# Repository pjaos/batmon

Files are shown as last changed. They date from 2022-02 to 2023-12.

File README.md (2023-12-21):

# BATMON

## Overview
The batmon device connects to a Lithium ION battery (primarily aimed at Ebike batteries) and allows the user to
trade off the lifetime of the battery against the maximum single charge. The life of a lithium ION cell
is affected by many things, the maximum charge level of the cell, the temperature of the cell, the maximum
discharge of the cell etc. The batmon device allows the user to limit the maximum charge voltage of the cell
to reduce stresses on the battery chemistry.

For example if the maximum charge voltage of a Lithium ION cell is set to 4.1
volts per cell rather than the maximum of 4.2 volts per cell then the number of charge/discharge cycles
that the battery is capable of could be doubled. The trade off for this is that you will loose about 10 %
of the range on a single charge. If set to 4.0 volts per cell then the number of charge/discharge cycles
that the battery is capable of could be increased by four times. The trade off for this is that you will
loose about 25 % of the range on a single charge. The batmon device allows the user to set this trade off
by selecting the maximum charge voltage in five 0.05 volt steps from 4.2 to 4.0 volts.

The device also ensures that the battery is not charged when to cold or hot which also limits the batteries
lifetime. Charging at temperatures of 0°C or below can also be dangerous.

As stated previously this project is primarily aimed at improving the lifetime of Ebike batteries although the hardware could be used for other battery voltages with slight changes to the software. The device provides a WiFi connection. This can connect to your home WiFi network or run in stand alone (AP) mode. The [Yview App](https://github.com/pjaos/yview/tree/master/gui) can be used (Android phone/tablet or a Windows, Linux PC) to access the state of the battery (charge voltage/current etc) and configure the device settings.

## System Requirements
An initial set of requirements for the system is shown below.

* Charge the battery to a maximum voltage of between 4.0 and 4.2 Volts, configurable by the user.
* Display the charge voltage, current and power.
* Turn off charging if the battery temperature is too cold (<= 0°C).
* Turn off charging if the battery temperature is too hot (> 45°C)g.

## Hardware.
The hardware design uses an ESP32 CPU which provides the WiFi connectivity. An ADS1115 I2C 16 bit ADC device is used to measure the battery voltage, charge current and battery temperature. A Mosfet is used to turn off the battery charge once it reaches the configured charge voltage. The case for the module was 3D printed to provide a robust mount for the module inside the battery case.

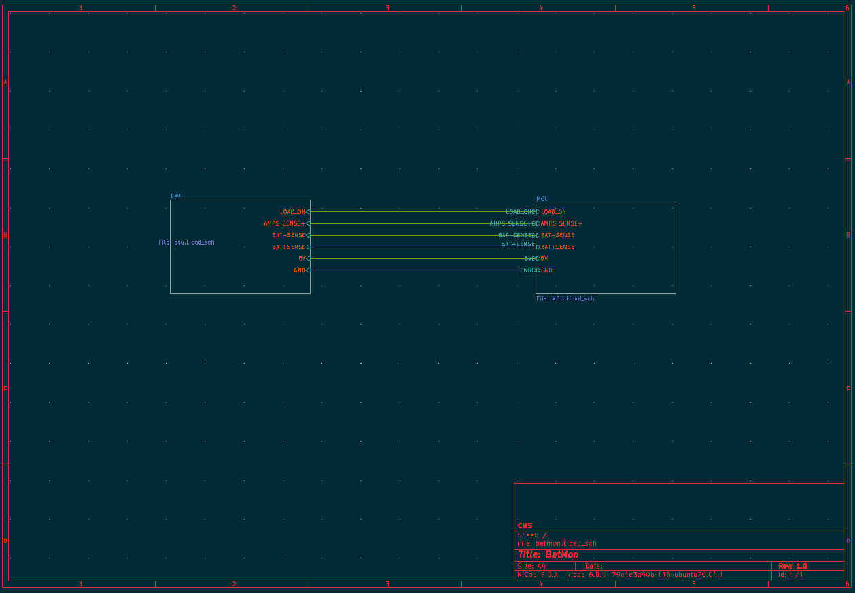
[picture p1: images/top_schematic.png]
Top Level Schematic

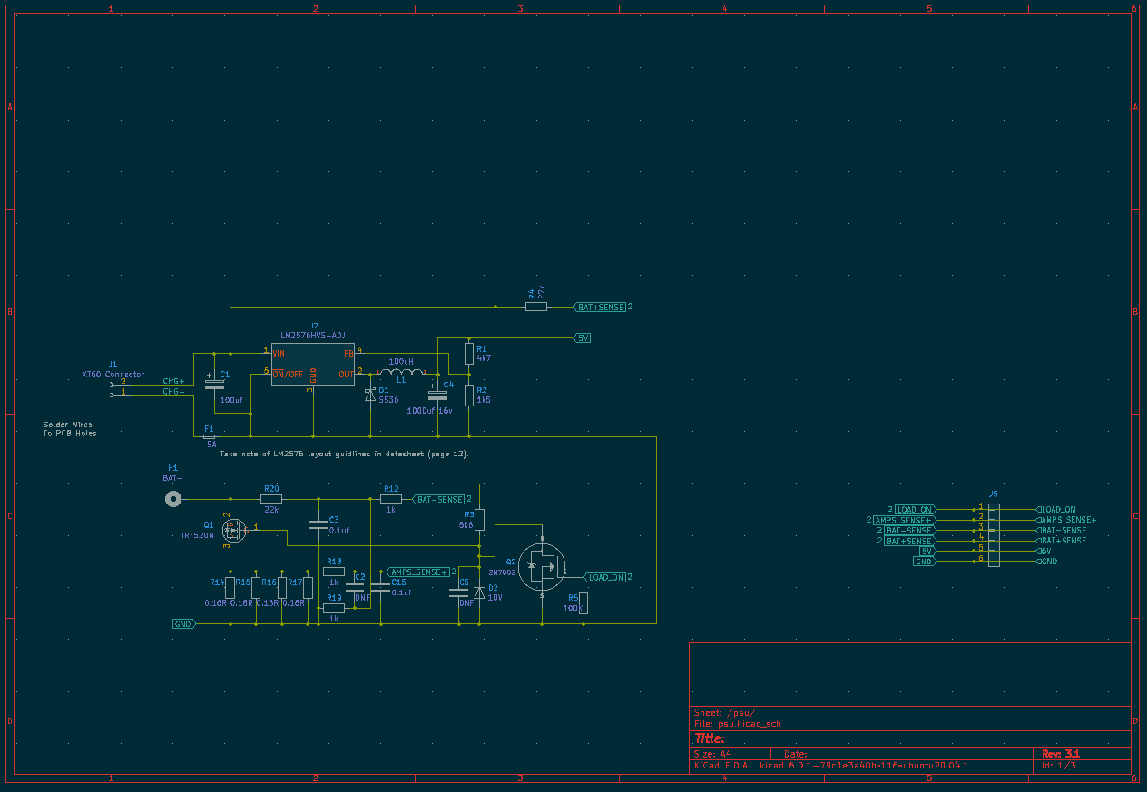
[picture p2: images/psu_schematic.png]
Top Level Schematic PSU Schematic

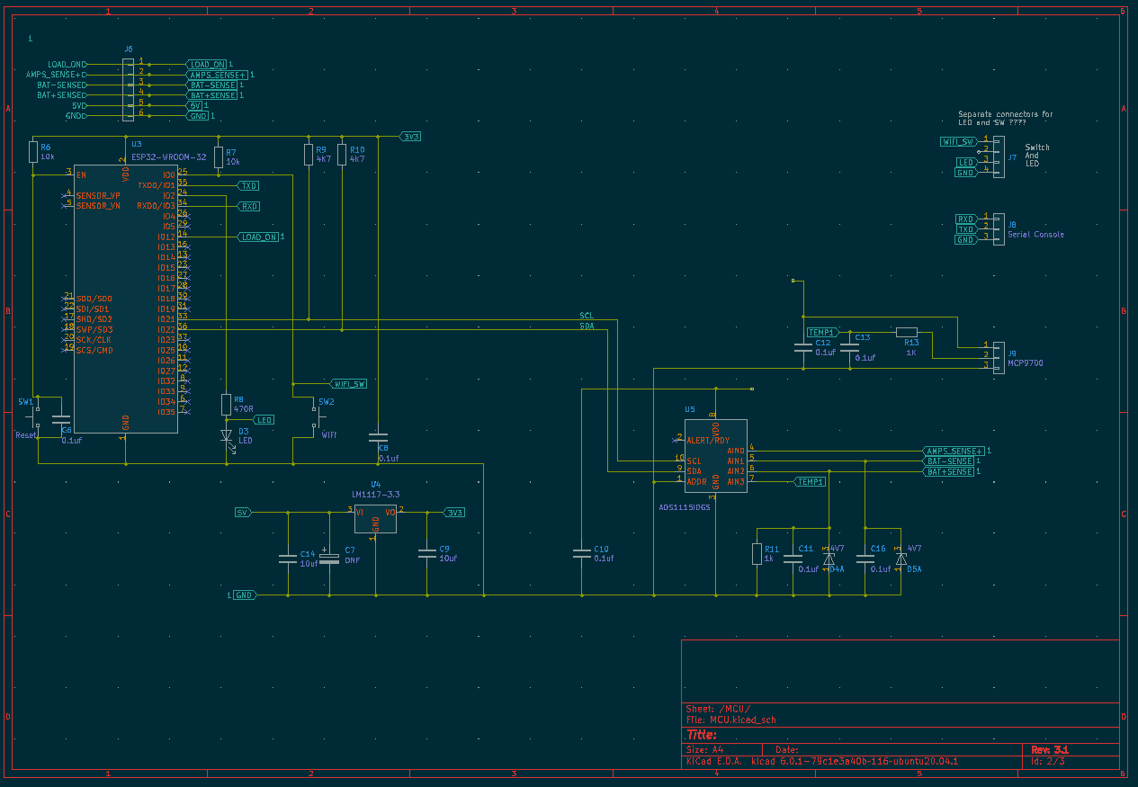
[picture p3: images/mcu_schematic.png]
Top Level Schematic MCU Schematic

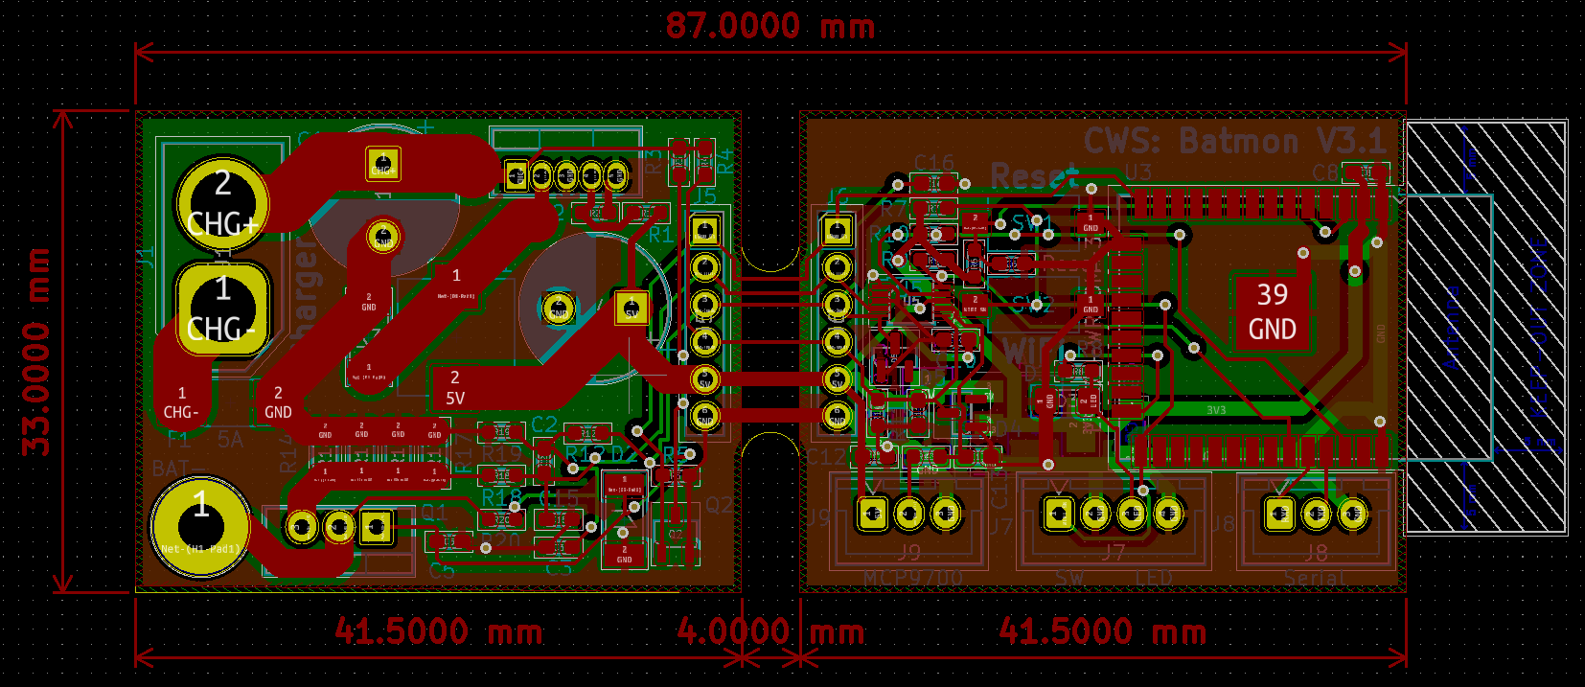
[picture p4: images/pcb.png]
PCB
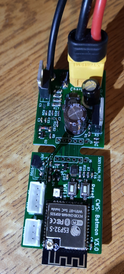
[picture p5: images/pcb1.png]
PCB PCB Assembled
 
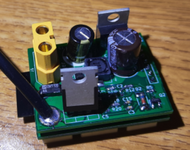
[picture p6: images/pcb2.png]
PCB PCB Assembled (Reduced Size, Side 1)

PCB PCB Assembled (Side 2)

Module installed into case in charger lead.

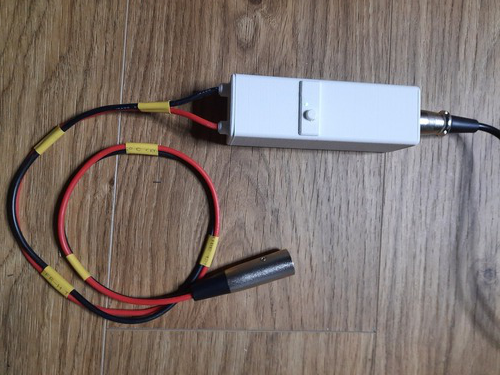
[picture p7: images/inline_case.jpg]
PCB PCB Assembled (Inserting into case)


Module installed inside Ebike battery box.

PCB PCB Assembled (Inserting into case)
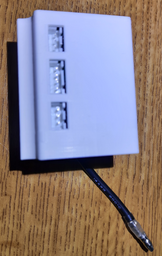
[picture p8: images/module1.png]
PCB Module Assembled (Side 2)

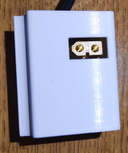
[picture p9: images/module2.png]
PCB Module Assembled (Side 1)

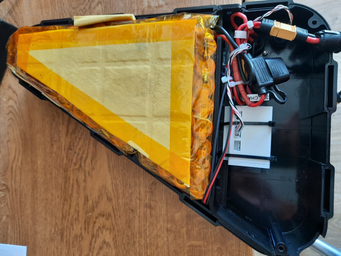
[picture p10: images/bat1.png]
PCB Module Installed in battery.


## Software
The software that runs on the device is written in C and uses the [Mongoose OS](https://mongoose-os.com/).
It provides a web interface and integrates with the [YView](https://github.com/pjaos/yview) Iot archetecture.
The web interface is shown below.
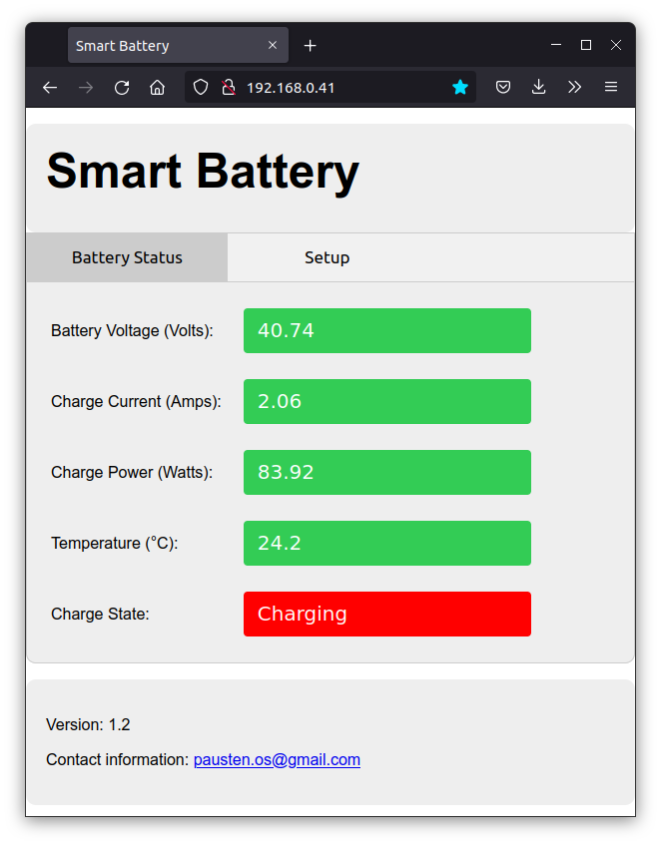
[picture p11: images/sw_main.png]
PCB Main Web interface.

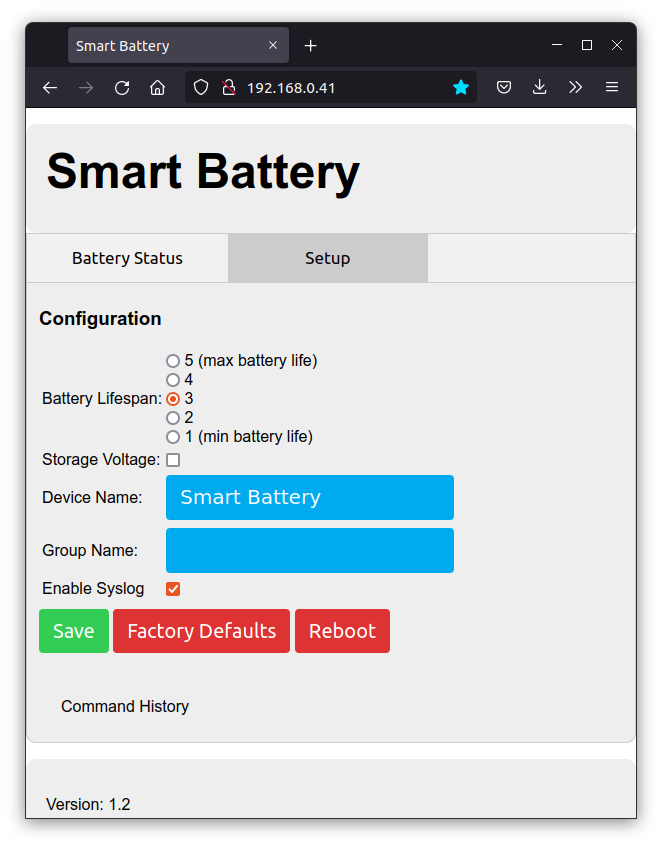
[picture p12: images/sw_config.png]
PCB Configuration interface.


The configuration page allow the user to trade off battery charge level against
the longevity of the battery pack via the 5 radio buttons at the top of the page.
 * 5 = max battery life but only charges the battery pack to 4 volts per cell.
 * 1 = min battery life but charges the battery pack to 4.2 volts per cell.

 The default is 3 with charges the battery pack to 4.1 volts per cell. This
 setting should approximately double the life (number of charge discharge cycles) when
 compared option 1. EBike battery chargers will normally charge a battery pack to this level. If option 5 is selected then the life of the battery should be approximately 4 times longer when compared to option 1.

The storage voltage checkbox can be selected if the user wishes to store the ebike for some time (E.G through the winter) and maximise the battery performance. This charges the battery to 3.7 volts.

The Device name can be set which sets the name that the device will appear as in the YView Iot network.

The group name can be set if the user wishes to partition the Iot network such that some users can see some devices.

The Enable syslog option is used for debugging and sends debugging information via the syslog protocol to the server running the YView Iot gateway process.

The save button will apply the configuration selected. The other buttons names are self explanatory.

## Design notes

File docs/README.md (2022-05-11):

# ebike Batmon
A Wifi enabled battery charge monitor. 

## Initial Requirements
- Monitor the following parameters while a 36V LION battery is being charged.

  - Battery voltage
  - Charge Current
  - Battery temperature
  - Provide the ability to stop the battery charging when it has reached 
    the required state.
  - Provide a web interface to view the state of the charge and adjust parameters.
  - Store the date/time and watt hours delivered on charge. This would need a max
    limit on charge sample storage (optional).
  - Graph the charge capacity in watt hours (optional).
  - Allow user to adjust max charge voltage.

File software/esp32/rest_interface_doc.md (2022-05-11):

# REST interface documentation.
The unit has a REST interface. The following documentation details
this interface. The examples here show the unit IP address which
may change.

#Calling rest IF

curl http://192.168.0.34/rpc/debug -d '{"level":2}'
2

curl http://192.168.0.34/rpc/factorydefault

curl http://192.168.0.34/rpc/load -d '{"on":1}'
0
curl http://192.168.0.34/rpc/load -d '{"on":0}'
1

curl http://192.168.0.41/rpc/set_amps_cal -d '{"codes_per_amp":5112}'
1512
5135

curl http://192.168.0.41/rpc/set_pvolts_cal -d '{"codes_per_volt":691}'
691

curl http://192.168.0.41/rpc/set_nvolts_cal -d '{"codes_per_volt":691}'
691

curl http://192.168.0.34/rpc/set_max_battery_charge -d '{"level":2}'
2

curl http://192.168.0.34/rpc/get_state
{"amps":0.001,"volts":22.006,"temperature":154.5}

### This causes the syslog output to be sent to the server the YView AYT message was received from
curl http://192.168.0.34/rpc/ydev.update_syslog
null

# Reboot the device
curl http://192.168.0.34/rpc/sys.reboot

curl http://192.168.0.34/rpc/rpc.list
["debug","update_syslog","factorydefault","WiFi.SetupComplete","WiFi.Scan","I2C.WriteRegW","I2C.WriteRegB","I2C.ReadRegW","I2C.ReadRegB","I2C.Write","I2C.Read","I2C.Scan","FS.Umount","FS.Mount","FS.Mkfs","FS.Rename","FS.Remove","FS.Put","FS.Get","FS.ListExt","FS.List","Config.Save","Config.Set","Config.Get","Sys.SetDebug","Sys.GetInfo","Sys.Reboot","RPC.Ping","RPC.Describe","RPC.List"]

curl http://192.168.0.34/rpc/Sys.GetInfo
{"id": "esp32_BA8DB5", "app": "esp32.git", "fw_version": "1.0", "fw_id": "2025629-085437/g2805f19-master-dirty", "mg_version": "2.19.1", "mg_id": "2025629-072504/2.19.1-gd52032f", "mac": "B4E62DBA8DB5", "arch": "esp32", "uptime": 540, "public_key": null, "ram_size": 281872, "ram_free": 221412, "ram_min_free": 208668, "fs_size": 233681, "fs_free": 144576,"wifi": {"sta_ip": "192.168.0.34", "ap_ip": "", "status": "got ip", "ssid": "airstorm11"}}

curl http://192.168.0.34/rpc/Config.Get
{"debug":{"udp_log_addr":"","udp_log_level":3,"mbedtls_level":1,"level":0,"file_level":"","event_level":2,"stdout_uart":0,"stderr_uart":0,"factory_reset_gpio":-1,"mg_mgr_hexdump_file":""},"i2c":{"unit_no":0,"enable":true,"freq":400000,"debug":false,"sda_gpio":22,"scl_gpio":21},"i2c1":{"unit_no":1,"enable":false,"freq":400000,"debug":false,"sda_gpio":22,"scl_gpio":23},"device":{"id":"esp32_BA8DB5","license":"","mac":"","public_key":"","sn":""},"sys":{"tz_spec":"","wdt_timeout":30,"pref_ota_lib":""},"conf_acl":"*","http":{"enable":true,"listen_addr":"80","document_root":"/","index_files":"","ssl_cert":"","ssl_key":"","ssl_ca_cert":"","upload_acl":"*","hidden_files":"","auth_domain":"","auth_file":"","extra_headers":""},"update":{"timeout":600,"commit_timeout":0,"url":"","interval":0,"extra_http_headers":"","ssl_ca_file":"ca.pem","ssl_client_cert_file":"","ssl_server_name":"","enable_post":true},"rpc":{"enable":true,"http_enable":true,"service_sys_enable":true,"max_frame_size":4096,"max_queue_length":25,"default_out_channel_idle_close_timeout":10,"acl_file":"","auth_domain":"RPC","auth_file":"","uart":{"uart_no":0,"baud_rate":115200,"fc_type":2,"dst":""}},"spi":{"enable":false,"debug":false,"unit_no":3,"miso_gpio":19,"mosi_gpio":23,"sclk_gpio":18,"cs0_gpio":5,"cs1_gpio":-1,"cs2_gpio":-1},"syslog":{"url":"udp://192.168.0.8:514","hostname":"BATMON1"},"wifi":{"ap":{"enable":false,"ssid":"Mongoose_??????","pass":"12345678","hidden":false,"channel":6,"max_connections":10,"ip":"192.168.4.1","netmask":"255.255.255.0","gw":"192.168.4.1","dhcp_start":"192.168.4.2","dhcp_end":"192.168.4.100","trigger_on_gpio":-1,"disable_after":0,"hostname":"","keep_enabled":true,"bandwidth_20mhz":false,"protocol":"BGN"},"sta":{"enable":true,"ssid":"airstorm11","pass":"XXXXXXXX","user":"","anon_identity":"","cert":"","key":"","ca_cert":"","ip":"","netmask":"","gw":"","nameserver":"","dhcp_hostname":"","protocol":"BGN","listen_interval_ms":0},"sta1":{"enable":false,"ssid":"","pass":"","user":"","anon_identity":"","cert":"","key":"","ca_cert":"","ip":"","netmask":"","gw":"","nameserver":"","dhcp_hostname":"","protocol":"BGN","listen_interval_ms":0},"sta2":{"enable":false,"ssid":"","pass":"","user":"","anon_identity":"","cert":"","key":"","ca_cert":"","ip":"","netmask":"","gw":"","nameserver":"","dhcp_hostname":"","protocol":"BGN","listen_interval_ms":0},"sta_cfg_idx":0,"sta_connect_timeout":30,"sta_ps_mode":0,"sta_all_chan_scan":true},"platform":{"wifi_button_gpio":0,"wifi_led_gpio":2},"user":{"setup_mode":0,"wifi_mode":1,"product_id":"BATMON"},"ydev":{"product_id":"BATMON","unit_name":"BATMON1","group_name":"","enable_syslog":false},"ydevayth":{"hashtag":"-!#8[dkG^v's!dRznE}6}8sP9}QoIR#?O&pg)Qra"},"board":{"led1":{"pin":13,"active_high":true},"led2":{"pin":-1,"active_high":true},"led3":{"pin":-1,"active_high":true},"btn1":{"pin":0,"pull_up":true},"btn2":{"pin":-1,"pull_up":false},"btn3":{"pin":-1,"pull_up":false}}}

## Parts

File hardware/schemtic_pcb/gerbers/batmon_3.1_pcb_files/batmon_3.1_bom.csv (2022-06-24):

Comment | Designator | Footprint | LCSC
100uf | C1 | Capacitor_THT:CP_Radial_D10.0mm_P5.00mm
DNF | C2,C5 | Capacitor_SMD:C_0603_1608Metric_Pad1.08x0.95mm_HandSolder
0.1uf | C3,C6,C8,C10,C11,C12,C13,C15,C16 | Capacitor_SMD:C_0603_1608Metric_Pad1.08x0.95mm_HandSolder | C14663
1000uf 16v | C4 | Capacitor_THT:CP_Radial_D10.0mm_P5.00mm
DNF | C7 | Capacitor_Tantalum_SMD:CP_EIA-6032-20_AVX-F_Pad2.25x2.35mm_HandSolder
10uf | C9,C14 | Capacitor_SMD:C_1206_3216Metric_Pad1.33x1.80mm_HandSolder
SS36 | D1 | Diode_SMD:D_MELF | C35722
10V | D2 | Diode_SMD:D_MELF | C50975
LED | D3 | Diode_SMD:D_1206_3216Metric_Pad1.42x1.75mm_HandSolder
4V7 | D4,D5 | Package_TO_SOT_SMD:SOT-23 | C18206
5A | F1 | PJA_Fuses:Scherter_OMT125 | nn
BAT- | H1 | MountingHole:MountingHole_3.2mm_M3_Pad
XT60 Connector | J1 | Connector_AMASS:AMASS_XT60-F_1x02_P7.20mm_Vertical
Conn_01x06 | J5,J6 | Connector_PinHeader_2.54mm:PinHeader_1x06_P2.54mm_Vertical
SW_&_LED | J7 | Connector_JST:JST_XH_B4B-XH-A_1x04_P2.50mm_Vertical
Serial Console | J8 | Connector_JST:JST_XH_B3B-XH-A_1x03_P2.50mm_Vertical
MCP9700 | J9 | Connector_JST:JST_XH_B3B-XH-A_1x03_P2.50mm_Vertical
100uH | L1 | PJA_Inductors:Sumida_CDRH74 | C85276
IRF520N | Q1 | Package_TO_SOT_THT:TO-220-3_Vertical
2N7002 | Q2 | Package_TO_SOT_SMD:TSOT-23 | C8545
4k7 | R1 | Resistor_SMD:R_0603_1608Metric_Pad0.98x0.95mm_HandSolder | C23162
1k | R11,R12,R18,R19 | Resistor_SMD:R_0603_1608Metric_Pad0.98x0.95mm_HandSolder | C21190
1K | R13 | Resistor_SMD:R_0603_1608Metric_Pad0.98x0.95mm_HandSolder | C21190
0.16R | R14,R15,R16,R17 | Resistor_SMD:R_1206_3216Metric_Pad1.30x1.75mm_HandSolder | C175786
1k5 | R2 | Resistor_SMD:R_0603_1608Metric_Pad0.98x0.95mm_HandSolder | C22843
5k6 | R3 | Resistor_SMD:R_0603_1608Metric_Pad0.98x0.95mm_HandSolder | C23189
22k | R4,R20 | Resistor_SMD:R_0603_1608Metric_Pad0.98x0.95mm_HandSolder | C31850
100K | R5 | Resistor_SMD:R_0603_1608Metric_Pad0.98x0.95mm_HandSolder | C25803
10k | R6,R7 | Resistor_SMD:R_0603_1608Metric_Pad0.98x0.95mm_HandSolder | C25804
470R | R8 | Resistor_SMD:R_0603_1608Metric_Pad0.98x0.95mm_HandSolder | C23179
4K7 | R9,R10 | Resistor_SMD:R_0603_1608Metric_Pad0.98x0.95mm_HandSolder | C23162
Reset | SW1 | PJA_Switches:switch_SPST_5mmx3mmx2.5mm
WiFi | SW2 | PJA_Switches:switch_SPST_5mmx3mmx2.5mm
LM2576HVS-ADJ | U2 | Package_TO_SOT_THT:TO-220-5_Vertical
ESP32-WROOM-32 | U3 | RF_Module:ESP32-WROOM-32
LM1117-3.3 | U4 | Package_TO_SOT_SMD:SOT-223-3_TabPin2
ADS1115IDGS | U5 | Package_SO:TSSOP-10_3x3mm_P0.5mm

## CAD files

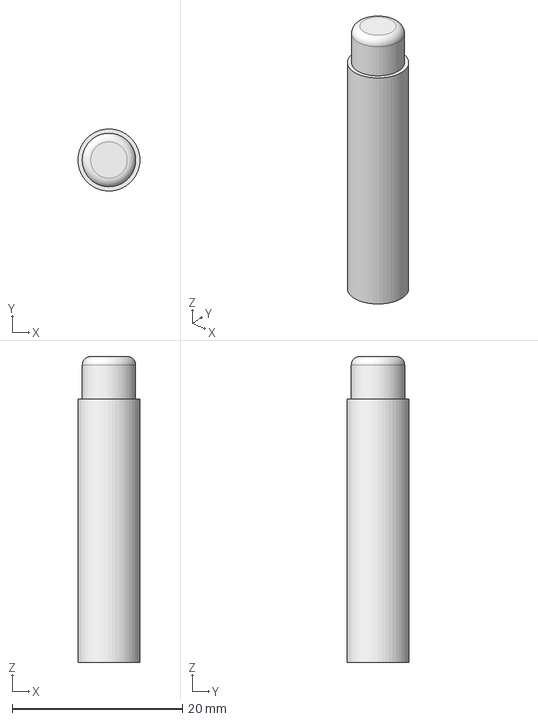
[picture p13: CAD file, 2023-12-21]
hardware/3d_printed_parts/button.FCStd
7.29 x 7.30 x 36.0 mm

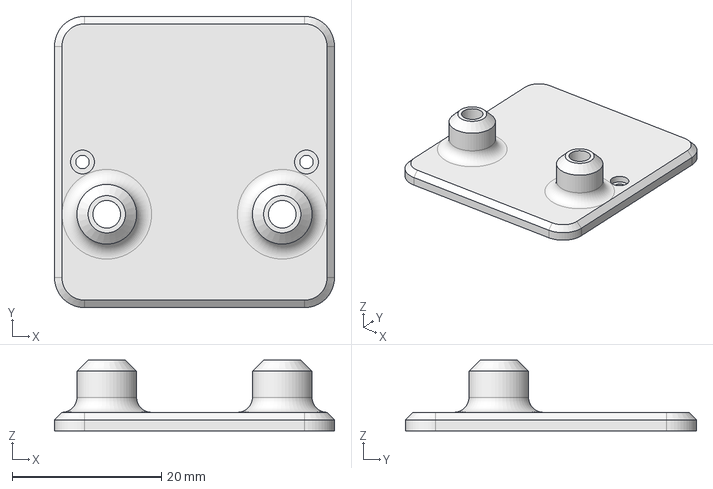
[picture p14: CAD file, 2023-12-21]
hardware/3d_printed_parts/inline_box_wire_end.FCStd
37.5 x 39.0 x 9.50 mm

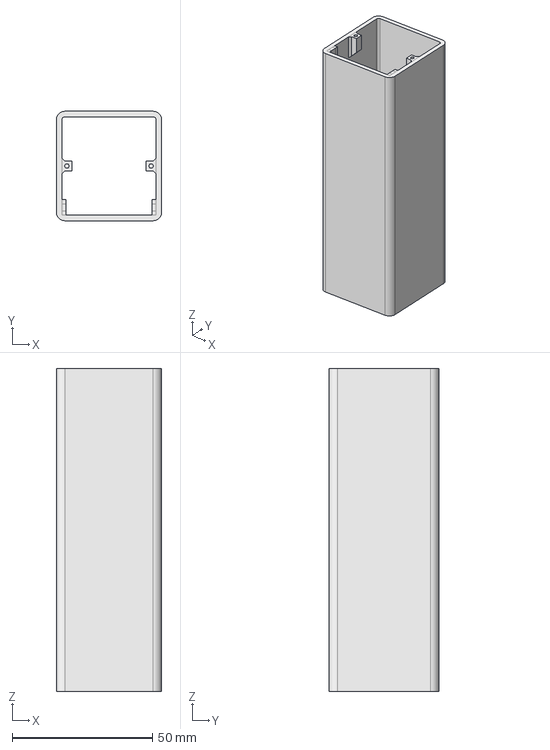
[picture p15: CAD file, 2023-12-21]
hardware/3d_printed_parts/inline_box.FCStd
37.5 x 39.0 x 115.0 mm

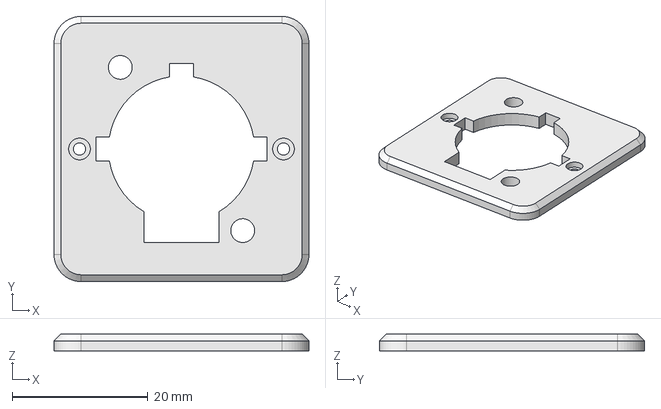
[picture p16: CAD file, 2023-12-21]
hardware/3d_printed_parts/inline_box_xlr_socket_end.FCStd
37.5 x 39.0 x 2.50 mm

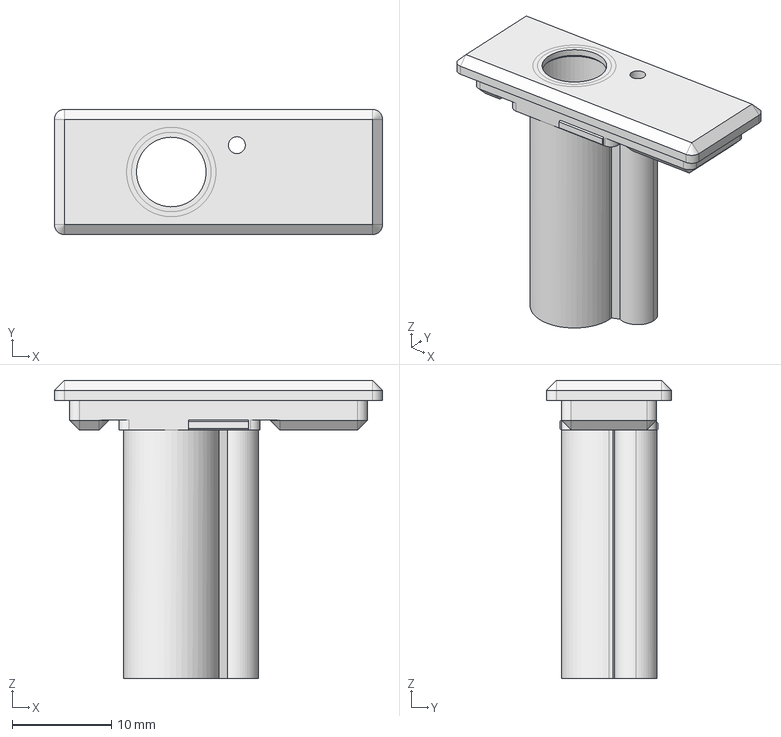
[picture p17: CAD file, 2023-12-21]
hardware/3d_printed_parts/sw_and_led_plate.FCStd
33.0 x 12.6 x 30.0 mm

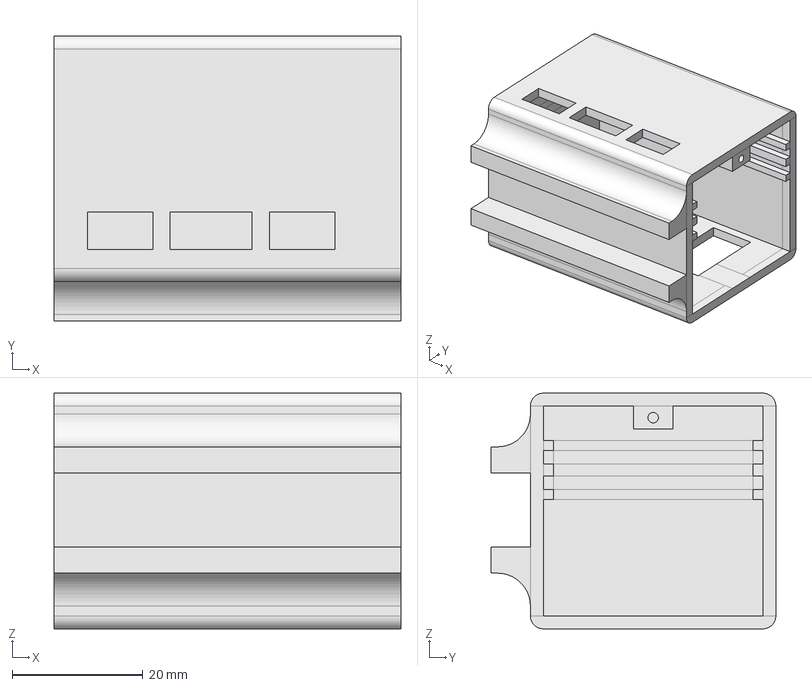
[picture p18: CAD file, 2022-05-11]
hardware/3d_printed_parts/case_mk3.FCStd
53.0 x 43.5 x 36.0 mm

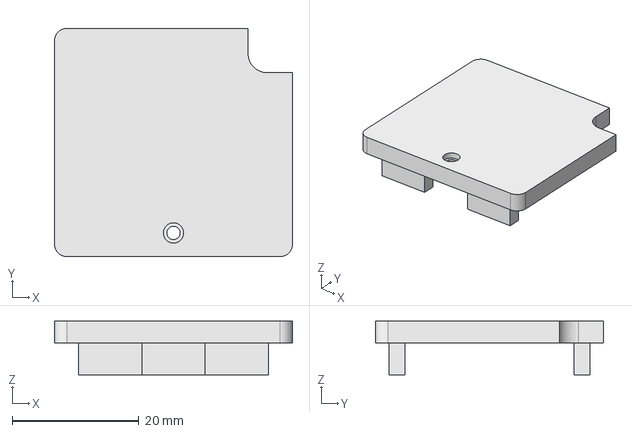
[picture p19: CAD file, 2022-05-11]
hardware/3d_printed_parts/top_mk1.FCStd
37.5 x 36.0 x 8.50 mm

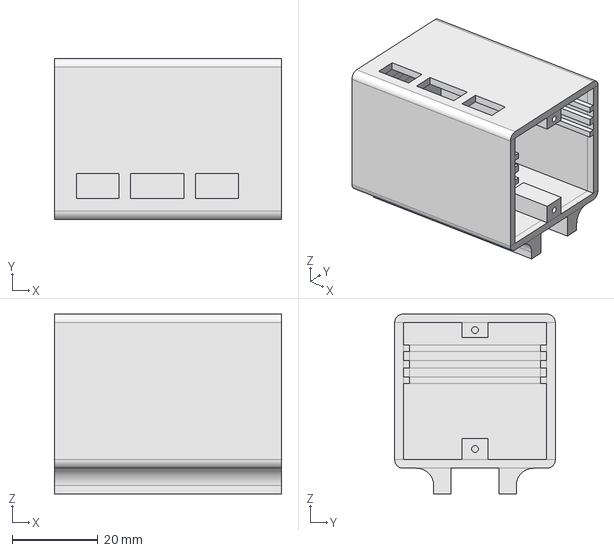
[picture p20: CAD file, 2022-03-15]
hardware/3d_printed_parts/case_mk2.FCStd
53.0 x 37.5 x 42.0 mm

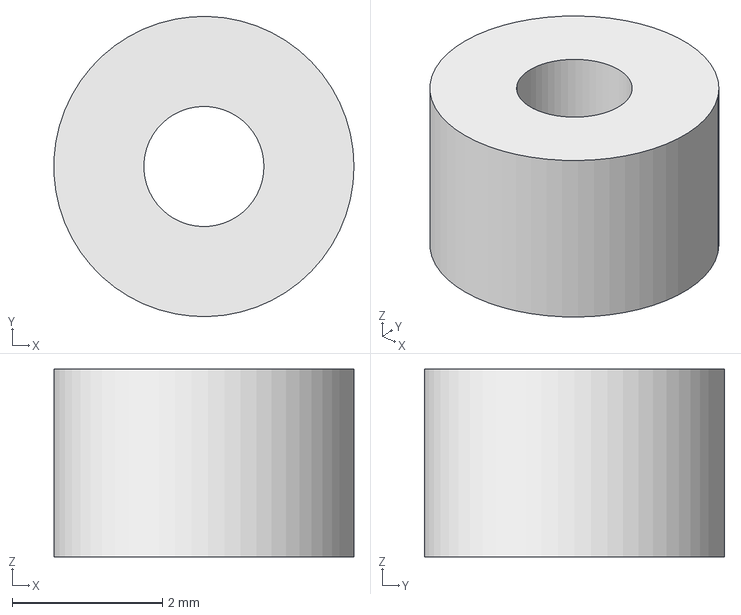
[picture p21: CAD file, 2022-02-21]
hardware/3d_printed_parts/standoff_1.FCStd
4.00 x 4.00 x 2.50 mm

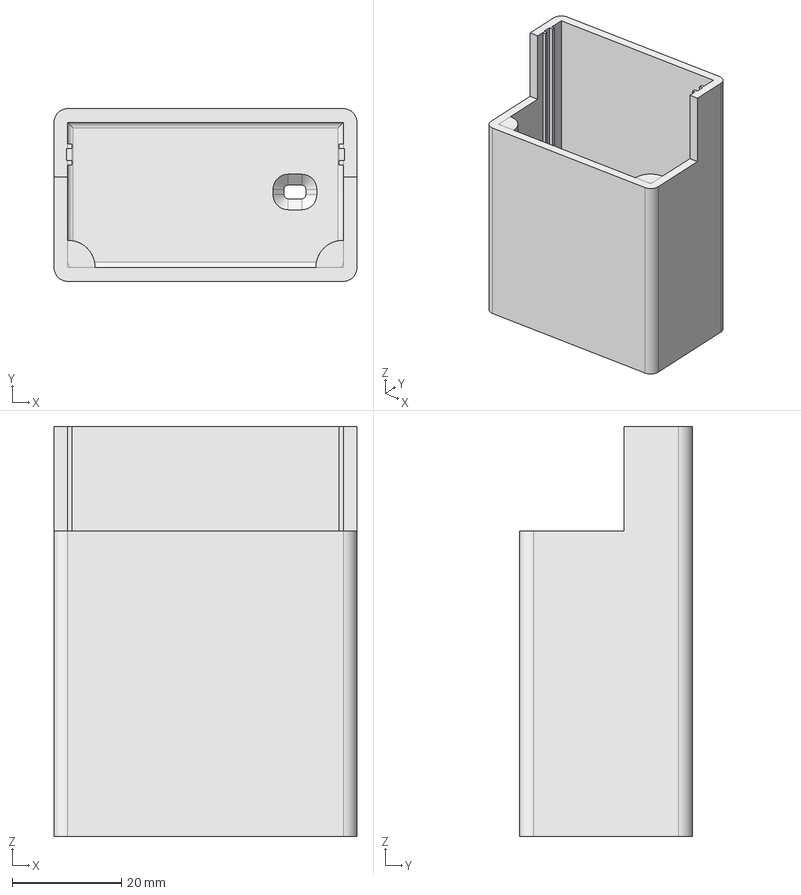
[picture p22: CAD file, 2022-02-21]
hardware/3d_printed_parts/debug_box_base_1.FCStd
55.4 x 31.6 x 75.0 mm

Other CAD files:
hardware/3d_printed_parts/case_mk4.FCStd
hardware/3d_printed_parts/case_mk1.FCStd

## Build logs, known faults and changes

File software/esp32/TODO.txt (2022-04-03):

- If temp is below zero and goes above zero then reboot
  to attempt to charge battery.
- If temp is above max temp and drops below max then reboot
  to attempt to charge battery.
- Exponential reboot time to check battery charge ?

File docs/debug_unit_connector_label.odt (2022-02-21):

5V

3V3

LOAD GPIO

I2C SCL

I2C SDA

GND

MCP9700 5V

VOUT

GND

5V

3V3 L+VE

GND GNDEE

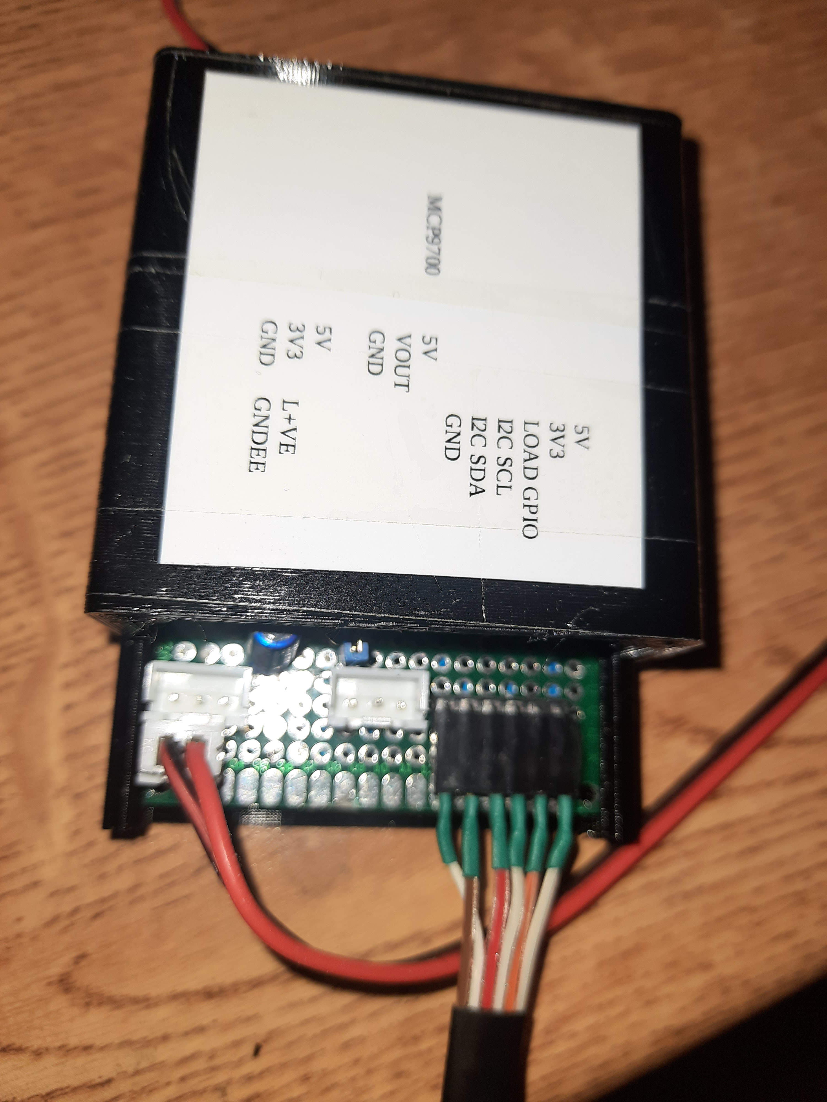
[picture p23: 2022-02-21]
docs/debug_unit.jpg

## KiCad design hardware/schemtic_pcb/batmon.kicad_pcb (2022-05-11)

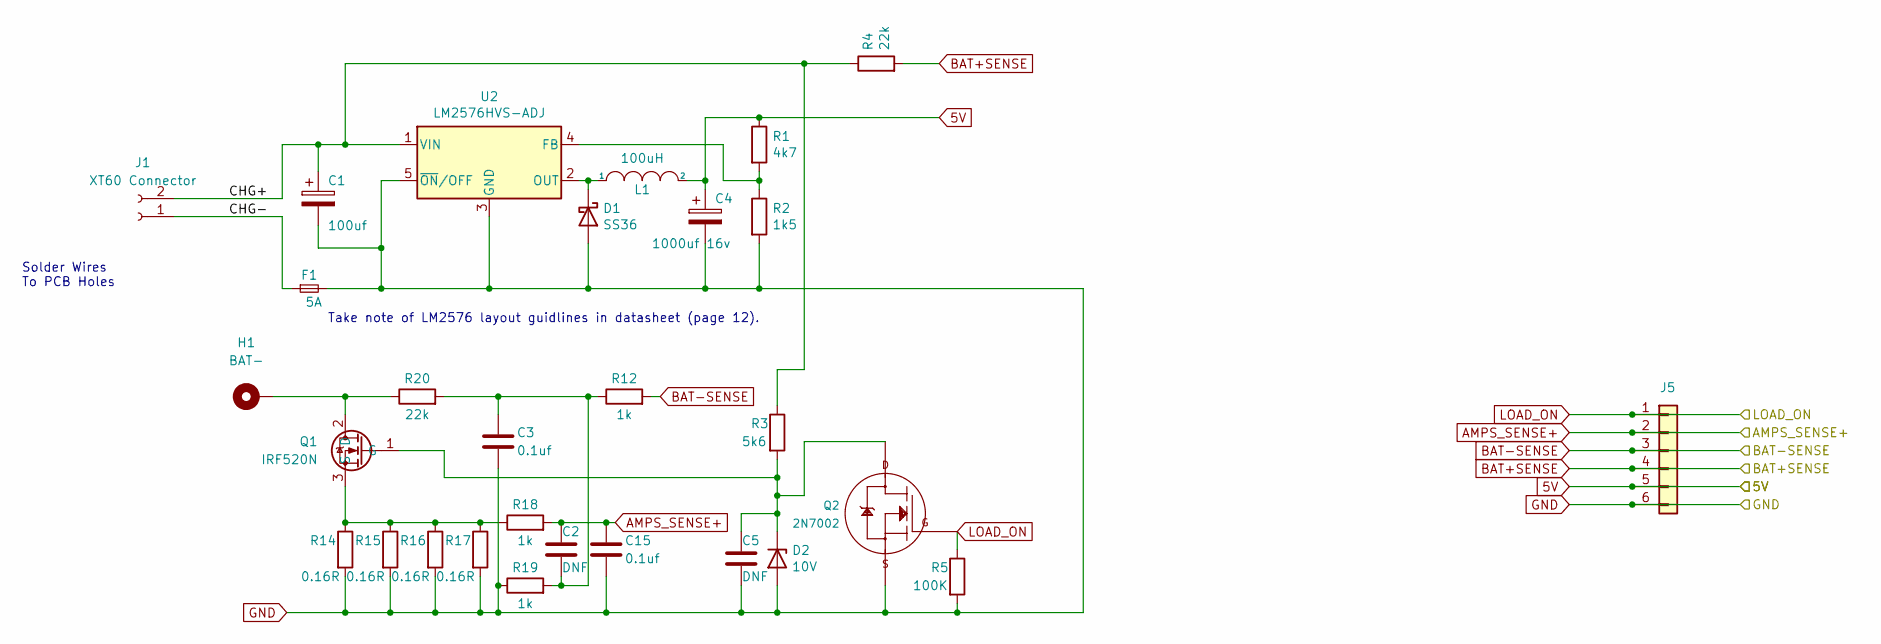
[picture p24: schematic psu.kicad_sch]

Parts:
C1: 100uf; CP_Radial_D10.0mm_P5.00mm
C2, C5: DNF; C_0603_1608Metric_Pad1.08x0.95mm_HandSolder
C3, C15: 0.1uf; C_0603_1608Metric_Pad1.08x0.95mm_HandSolder
C4: 1000uf 16v; CP_Radial_D10.0mm_P5.00mm
D1: SS36; D_MELF
D2: 10V; D_MELF
F1: 5A; Scherter_OMT125
H1: BAT-; MountingHole_3.2mm_M3_Pad
J1: XT60 Connector; AMASS_XT60-F_1x02_P7.20mm_Vertical
J5: Conn_01x06; PinHeader_1x06_P2.54mm_Vertical
L1: 100uH; Sumida_CDRH74
Q1: IRF520N; TO-220-3_Vertical
Q2: 2N7002; TSOT-23
R1: 4k7; R_0603_1608Metric_Pad0.98x0.95mm_HandSolder
R2: 1k5; R_0603_1608Metric_Pad0.98x0.95mm_HandSolder
R3: 5k6; R_0603_1608Metric_Pad0.98x0.95mm_HandSolder
R4, R20: 22k; R_0603_1608Metric_Pad0.98x0.95mm_HandSolder
R5: 100K; R_0603_1608Metric_Pad0.98x0.95mm_HandSolder
R12, R18, R19: 1k; R_0603_1608Metric_Pad0.98x0.95mm_HandSolder
R14, R15, R16, R17: 0.16R; R_1206_3216Metric_Pad1.30x1.75mm_HandSolder
U2: LM2576HVS-ADJ; TO-220-5_Vertical

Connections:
5V: C4.1, J5.5, L1.2, R1.1; also elsewhere on the board
/psu/CHG+: C1.1, J1.2, R3.1, R4.1, U2.1 (VIN)
/psu/CHG-: F1.1, J1.1
AMPS_SENSE+: C2.1, C15.1, J5.2, R18.2; also elsewhere on the board
BAT+SENSE: J5.4, R4.2; also elsewhere on the board
BAT-SENSE: J5.3, R12.2; also elsewhere on the board
GND: C1.2, C3.2, C4.2, C5.2, C15.2, D1.2 (A), D2.2 (A), F1.2, J5.6, Q2.2 (S), R2.2, R5.2, R14.2, R15.2, R16.2, R17.2, R19.1, U2.3 (GND), U2.5 (~ON/OFF); also elsewhere on the board
LOAD_ON: J5.1, Q2.1 (G), R5.1; also elsewhere on the board
unnamed: C2.2, C3.1, R12.1, R19.2, R20.2
unnamed: C5.1, D2.1 (K), Q1.1 (G), Q2.3 (D), R3.2
unnamed: D1.1 (K), L1.1, U2.2 (OUT)
unnamed: H1.1, Q1.2 (D), R20.1
unnamed: Q1.3 (S), R14.1, R15.1, R16.1, R17.1, R18.1
unnamed: R1.2, R2.1, U2.4 (FB)

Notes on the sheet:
Take note of LM2576 layout guidlines in datasheet (page 12).
Solder Wires To PCB Holes

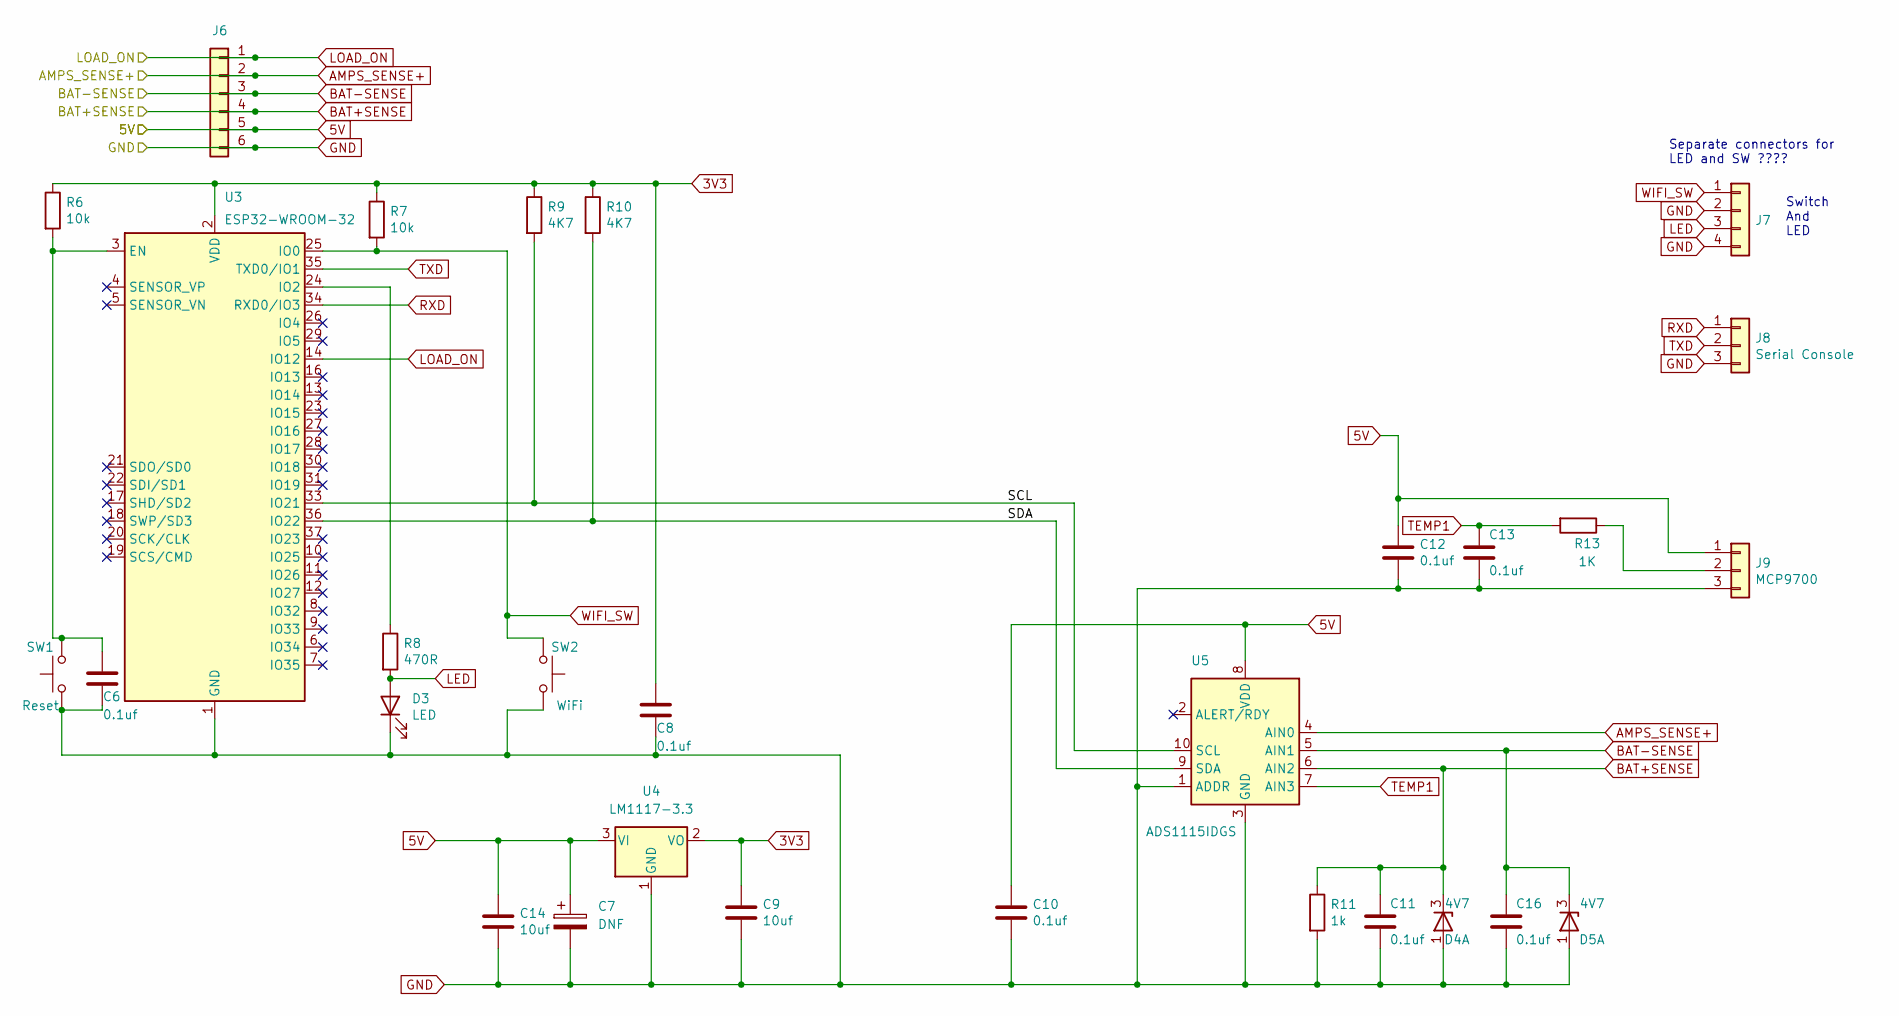
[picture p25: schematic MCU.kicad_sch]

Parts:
C6, C8, C10, C11, C12, C13, C16: 0.1uf; C_0603_1608Metric_Pad1.08x0.95mm_HandSolder
C7: DNF; CP_EIA-6032-20_AVX-F_Pad2.25x2.35mm_HandSolder
C9, C14: 10uf; C_1206_3216Metric_Pad1.33x1.80mm_HandSolder
D3: LED; D_1206_3216Metric_Pad1.42x1.75mm_HandSolder
D4, D5: 4V7; SOT-23
J6: Conn_01x06; PinHeader_1x06_P2.54mm_Vertical
J7: SW_&_LED; JST_XH_B4B-XH-A_1x04_P2.50mm_Vertical
J8: Serial Console; JST_XH_B3B-XH-A_1x03_P2.50mm_Vertical
J9: MCP9700; JST_XH_B3B-XH-A_1x03_P2.50mm_Vertical
R6, R7: 10k; R_0603_1608Metric_Pad0.98x0.95mm_HandSolder
R8: 470R; R_0603_1608Metric_Pad0.98x0.95mm_HandSolder
R9, R10: 4K7; R_0603_1608Metric_Pad0.98x0.95mm_HandSolder
R11: 1k; R_0603_1608Metric_Pad0.98x0.95mm_HandSolder
R13: 1K; R_0603_1608Metric_Pad0.98x0.95mm_HandSolder
SW1: Reset; switch_SPST_5mmx3mmx2.5mm
SW2: WiFi; switch_SPST_5mmx3mmx2.5mm
U3: ESP32-WROOM-32
U4: LM1117-3.3; SOT-223-3_TabPin2
U5: ADS1115IDGS; TSSOP-10_3x3mm_P0.5mm

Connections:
3V3: C8.1, C9.1, R6.1, R7.1, R9.1, R10.1, U3.2 (VDD), U4.2 (VO)
5V: C7.1, C10.1, C12.1, C14.1, J6.5, J9.1, U4.3 (VI), U5.8 (VDD); also elsewhere on the board
/MCU/SCL: R9.2, U3.33 (IO21), U5.10 (SCL)
/MCU/SDA: R10.2, U3.36 (IO22), U5.9 (SDA)
AMPS_SENSE+: J6.2, U5.4 (AIN0); also elsewhere on the board
BAT+SENSE: C11.1, D4.3 (K), J6.4, R11.1, U5.6 (AIN2); also elsewhere on the board
BAT-SENSE: C16.1, D5.3 (K), J6.3, U5.5 (AIN1); also elsewhere on the board
GND: C6.2, C7.2, C8.2, C9.2, C10.2, C11.2, C12.2, C13.2, C14.2, C16.2, D3.1 (K), D4.1 (A), D5.1 (A), J6.6, J7.2, J7.4, J8.3, J9.3, R11.2, SW1.1, SW2.1, U3.1 (GND), U3.15 (GND), U3.38 (GND), U3.39 (GND), U4.1 (GND), U5.1 (ADDR), U5.3 (GND); also elsewhere on the board
LED: D3.2 (A), J7.3, R8.2
LOAD_ON: J6.1, U3.14 (IO12); also elsewhere on the board
unnamed: C6.1, R6.2, SW1.2, U3.3 (EN)
unnamed: J9.2, R13.1
unnamed: R8.1, U3.24 (IO2)
RXD: J8.1, U3.34 (RXD0/IO3)
TEMP1: C13.1, R13.2, U5.7 (AIN3)
TXD: J8.2, U3.35 (TXD0/IO1)
WIFI_SW: J7.1, R7.2, SW2.2, U3.25 (IO0)

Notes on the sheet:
Switch And LED
Separate connectors for LED and SW ????

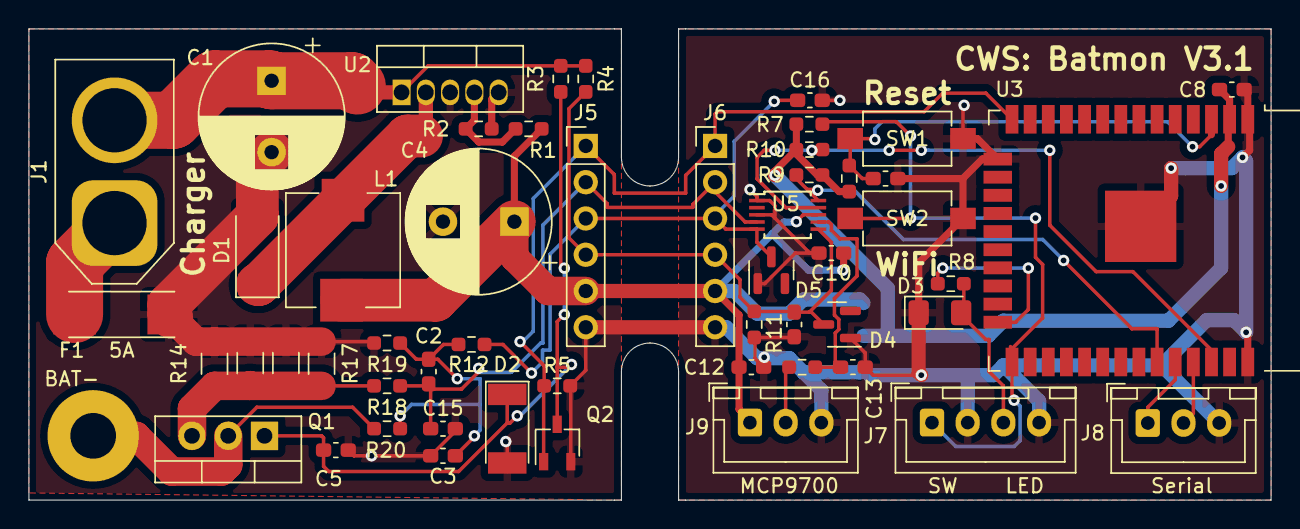
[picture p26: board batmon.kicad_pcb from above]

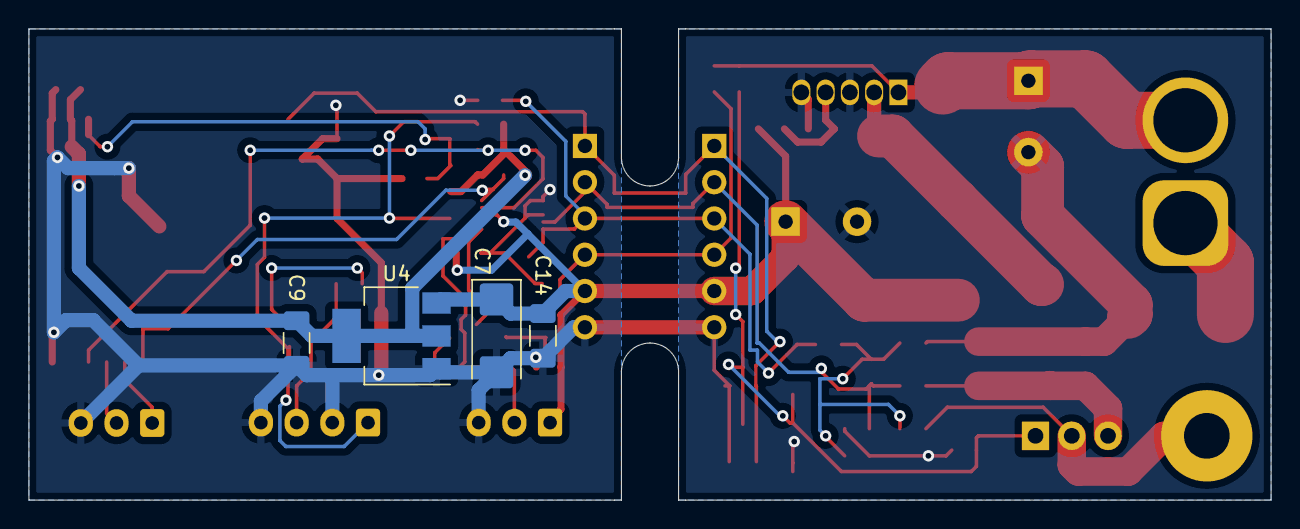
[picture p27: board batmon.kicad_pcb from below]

Board: 2 copper layers, 87.0 x 33.0 mm, 58 parts (4 on the bottom side), 25 nets.

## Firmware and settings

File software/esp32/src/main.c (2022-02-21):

#include <mgos.h>
#include <ydev_ayt_handler.h>
#include "mgos_syslog.h"
#include "ayt_tx_handler.h"
#include "rpc_handler.h"
#include "timer.h"
#include "logger.h"
#include "gpio.h"
#include "restart.h"

/**
 * @brief Initialises the application.
 **/
enum mgos_app_init_result mgos_app_init(void) {
    restart_init();

    gpio_init();

    rpc_init();

    add_ayt_response_handler(send_ayt_response);

    init_timers();

    logger("AYT HASHTAG: %s", (char *)mgos_sys_config_get_ydevayth_hashtag() );

    return MGOS_APP_INIT_SUCCESS;
}

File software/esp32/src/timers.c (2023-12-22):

#include <mgos.h>
#include <ads111x.h>

#include "timer.h"
#include "logger.h"
#include "gpio.h"
#include "esp_sleep.h"
#include "battery.h"

#define SHOW_TEMP_DEBUG 1
#define SHOW_VOLTS_DEBUG 1
#define SHOW_AMPS_DEBUG 1

#define READ_ADC_PERIOD_MS 1000
#define ADS111X_I2C_ADDRESS 72
#define ADC_READING_COUNT 3

#define MAX_LOGGER_BUFFER_LEN 129

#define STATUS_MSG_LENGTH 256

#define MIN_BATTERY_TEMP 0.0
#define MAX_BATTERY_TEMP 60.0

#define CHECK_CHARGE_PERIOD_SECS 3600*5

#define BAT_CHARGE_EVAL_SECS 10

static float tempC                  = 1000000;
static float pos_bat_voltage        = 1000000;
static float neg_bat_voltage        = 1000000;
static float amps                   = 1000000;
static float lastOnChargeVoltage    = 1000000;
static float battery_voltage        = 1000000;

static char warning_message[STATUS_MSG_LENGTH];

/**
 * @brief Get the status message.
 * @return The status message text.
 */
char *get_warning_message(void) {
    return warning_message;
}

/**
 * @brief Get the temperature in °C.
 * @return The temperature.
 */
float get_temp(void) {
    return tempC;
}

/**
 * @brief Get the voltage accross the battery in volts.
 * @return The voltage.
 */
float get_battery_voltage(void) {
    return battery_voltage;
}
/**
 * @brief Get the battery voltage the last time it was read while charging.
 * @return The voltage.
 */
float get_last_on_charge_voltage(void) {
    return lastOnChargeVoltage;
}

/**
 * @brief Get the currunet in amps.
 * @return The current.
 */
float get_current(void) {
    return amps;
}

/**
 * @brief Callback to send periodic updates of the memory and file system state.
 **/
static void timer1_cb(void *arg) {
    char *logger_buffer = get_logger_buffer();

    if( mgos_sys_config_get_ydev_enable_syslog() ) {
      size_t heap_zize          = mgos_get_heap_size();
      size_t free_heap_size     = mgos_get_free_heap_size();
      size_t min_free_heap_size = mgos_get_min_free_heap_size();
      size_t fs_size            = mgos_get_fs_size();
      size_t fs_free_size       = mgos_get_free_fs_size();

      snprintf(logger_buffer, MAX_LOGGER_BUFFER_LEN, "uptime: %.2lf, heap (size/free/min) %d/%d/%d, fs (size/free) %d/%d",  mgos_uptime(), heap_zize, free_heap_size, min_free_heap_size, fs_size, fs_free_size);
      logger(__FUNCTION__, logger_buffer);
    }

    if( mgos_uptime() > CHECK_CHARGE_PERIOD_SECS ) {
        snprintf(logger_buffer, MAX_LOGGER_BUFFER_LEN, "Restarting to check the battery charge voltage.");
        logger(__FUNCTION__, logger_buffer);
        mgos_system_restart_after(250);
    }

    (void) arg;
}

/**
 * @brief Read ADC value. Read the ADC a number of times and return the average value.
 * @param adc The ADC to read.
 * @param fs_voltage_id The ID of the max ADC voltage.
 * @param single_ended If 1 then read the ADC in single ended mode.
 * @return The ADC reading in two's compliment format.
 */
static int16_t read_adc(uint8_t adc, uint8_t fs_voltage_id, bool single_ended) {
    int16_t adc_value = 0;
    int32_t adc_value_accum = 0;
    uint8_t adc_value_index;

    for( adc_value_index=0 ; adc_value_index < ADC_READING_COUNT ; adc_value_index++ ) {
        adc_value = get_adc_twos_compliment_value(ADS111X_I2C_ADDRESS,
                                                  adc,
                                                  fs_voltage_id,
                                                  SAMPLES_PER_SECOND_32,
                                                  single_ended,
                                                  true);
        adc_value_accum += adc_value;
    }

    return (int16_t)(adc_value_accum/ADC_READING_COUNT);
}

/**
 * @brief Callback to periodically read amps adc.
 **/
static void read_adc_amps_cb(void *arg) {
    static int16_t amps_adc_load_off = 0;
    char *logger_buffer = get_logger_buffer();
    int16_t amps_adc = read_adc(ADC0, FS_VOLTAGE_0_256, true);
    snprintf(logger_buffer, MAX_LOGGER_BUFFER_LEN, "amps_adc=%d", amps_adc);
    logger(__FUNCTION__, logger_buffer);
    if ( is_load_on() ) {
        //If amps_adc_load_off value is not 0 then we have a no current adc value.
        if ( amps_adc_load_off && amps_adc > amps_adc_load_off ) {
            uint16_t adc_delta_codes = amps_adc-amps_adc_load_off;
            float codes_per_amp = (float)mgos_sys_config_get_batmon_codes_per_amp();
            if( codes_per_amp >= 0.0 ) {
                amps = (float)adc_delta_codes / codes_per_amp;
            }
            else {
                amps = 0.0;
            }
            //Apply min amps limit as no load will result in some ADC noise.
            if( amps < MIN_AMPS) {
                amps = 0.0;
            }
    #ifdef SHOW_AMPS_DEBUG
            snprintf(logger_buffer, MAX_LOGGER_BUFFER_LEN, "amps_adc_load_off=%d, adc_delta_codes=%d, amps=%.3f", amps_adc_load_off,
                                                                                                                  adc_delta_codes,
                                                                                                                  amps);
            logger(__FUNCTION__, logger_buffer);
    #endif
        }
    }
    else {
        amps_adc_load_off = amps_adc;
        amps = 0.0;
        logger(__FUNCTION__, "Load OFF");
    }

    (void) arg;
}

/**
 * @brief Callback to periodically read battery voltage.
 **/
static void read_bat_voltage(void *arg) {
    float max_charge_voltage            = get_max_charge_voltage();
    bool max_battery_charge_voltage_id  = get_max_battery_charge_voltage_id();
    float codes_per_volt                = (float)mgos_sys_config_get_batmon_nbat_codes_per_volt();
    char *logger_buffer                 = get_logger_buffer();
    int16_t pos_volts_adc               = read_adc(ADC2, FS_VOLTAGE_2_048, true);
    int16_t neg_volts_adc               = read_adc(ADC1, FS_VOLTAGE_2_048, true);

    if( codes_per_volt >= 0.0 ) {
        pos_bat_voltage = (float)pos_volts_adc/codes_per_volt;
        neg_bat_voltage = (float)neg_volts_adc/codes_per_volt;
    }
    else {
        pos_bat_voltage = 0.0;
    }
    // Calc the voltage accross the battery.
    battery_voltage = pos_bat_voltage - neg_bat_voltage;

    // If still charging store the battery voltage
    if( is_load_on() ) {
        lastOnChargeVoltage = battery_voltage;
    }

#ifdef SHOW_VOLTS_DEBUG
    snprintf(logger_buffer, MAX_LOGGER_BUFFER_LEN, "pvolts_adc=%d, pve_bat_voltage=%.3f, battery_voltage=%.3f", pos_volts_adc, pos_bat_voltage, battery_voltage);
    logger(__FUNCTION__, logger_buffer);
#endif

#ifdef SHOW_VOLTS_DEBUG
    snprintf(logger_buffer, MAX_LOGGER_BUFFER_LEN, "nvolts_adc=%d, nve_bat_voltage=%f", neg_volts_adc, neg_bat_voltage);
    logger(__FUNCTION__, logger_buffer);
#endif

    snprintf(logger_buffer, MAX_LOGGER_BUFFER_LEN, "max_battery_charge_voltage_id=%d", max_battery_charge_voltage_id);
    logger(__FUNCTION__, logger_buffer);
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

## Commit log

2022-02-21 Initial commit.
    [MCU.kicad_sch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]
2022-02-21 Rename folder esp32.git to esp32
2022-02-22 Add max cell voltages to config radio buttons.
2022-02-24 Disable charging if the battery is below 0 °C and display a warning message in the browser window.
2022-02-25 Add details of voltage per cell in the battery voltage tool tip text.
2022-03-11 Add message to show when battery charge is being checked. In the Voltage field report the last voltage on across the battery when it was last charged.
2022-03-11 Set battery charge check period to 1 hour Set charge eveal period to 10 seconds
2022-03-15 Bump schematic and PCB to version 3.0
    [MCU.kicad_sch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]
2022-03-15 Add version 3 of the PCB
2022-03-15 Add 3D printed case.
    [case_mk1.FCStd, case_mk2.FCStd]
2022-03-18 Change reboot time to every 5 hours.
    [timers.c]
2022-03-31 Fix unrouted R12 track that avoided DRC check
    [batmon.kicad_pcb]
2022-04-03 - Update ADC input protextion zenners from 3V9 to 4V7 volts - Fix unrouted track - Update PCB and schemtaic to v3.1
    [MCU.kicad_sch, batmon.kicad_pcb, batmon.kicad_sch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]
2022-04-04 - Set 2 decimal place resolution on amps, volts and watts. - Update default calibration values.
2022-04-15 Add an option to charge the battery to the LION storage voltage.
2022-04-15 - Add missing track (R12)
    [batmon.kicad_pcb]
2022-04-15 - Update schematic notes
    [psu.kicad_sch]
2022-04-15 - Return tp 10 cell (36V) battery pack as 7 cells used for testing on a 32 V PSU.
2022-04-21 Remove notes from schematic and pcb.
    [MCU.kicad_sch, psu.kicad_sch]
2022-05-11 Remove some docs from git and update readme doc.
    [calc_voltage_cal.ods]
2022-05-11 - Change Charge Voltage to Battery Voltage on web page. - Add smoothed voltage and current values. - Remove commented out debug code.
2022-05-11 - Ignore some folders and files created by kicad6. - Add pcb archive files.
2022-05-11 Add latest schematic and PCB.
    [MCU.kicad_sch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]
2022-05-11 Add latest case designs.
    [case_mk3.FCStd, case_mk4.FCStd, top_mk1.FCStd]
2022-05-11 Ignore csv and xml kicad output files.
2022-06-23 Update README to details the 3D printed case of the device.
2022-06-24 Save the latest PCB production files of all board versions.
    [batmon_3.1_bom.csv, batmon_top_placement.csv]
2022-06-24 Save the V3.1 gerber files from Kicad.
    [batmon-B_Cu.gbl, batmon-B_Mask.gbs, batmon-B_Paste.gbp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]
2022-06-24 Update git ignore with some of the tmp pcb files.
2023-12-21 Add inline box freecad files.
    [button.FCStd, inline_box.FCStd, inline_box_wire_end.FCStd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]
2023-12-21 Add inline case image.
2023-12-21 Add inline case image to project details.
2023-12-22 Set max charge temperature to 60C as now the module may be at ambient temperature if not connected directly to the battery the temperature limit of 45°C was too low.
    [timers.c]
